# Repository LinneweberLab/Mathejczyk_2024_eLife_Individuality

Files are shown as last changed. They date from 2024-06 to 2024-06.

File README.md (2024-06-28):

Repository for 3 behavioral assays currently in use by the Linneweber lab as described in the paper
“Individuality across environmental context in Drosophila melanogaster (Mathejczyk et al., 2023)". 
https://www.biorxiv.org/content/10.1101/2023.11.26.568741v1
<br>
<br>
This repository contains a part list for off-the-shelve parts, 3D printable files, visual stimulus files, and Matlab scripts for fly tracking and data analyisis.
<br>
<br>

1.	Flight simulator for studying vision-based decision making in flying flies, combining a 360° LED matrix with a magneto-tether apparatus

FlightSim

2.	Indytrax, a compact modular assay and tracker for high-throughput individual ethological quantification
	
IndyTrax

3.	Classical Buridan LED matrix assay

ClassicalBuridan

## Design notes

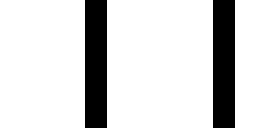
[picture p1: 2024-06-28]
Stripe Stimuli/30deg/30degstripe 0deg front.bmp

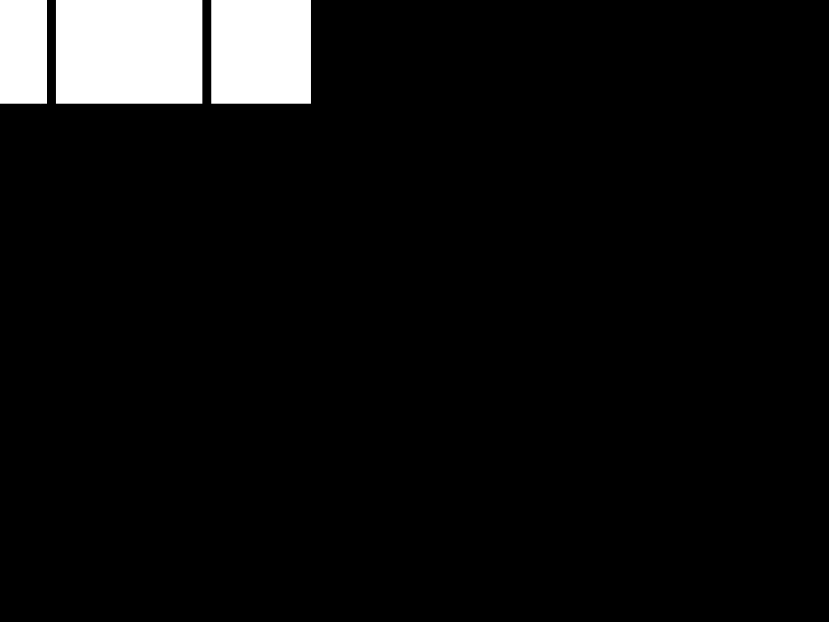
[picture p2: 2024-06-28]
Stripe Stimuli/12deg/BigCylinder 12degstripes Background3.bmp

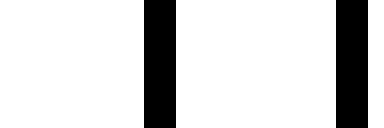
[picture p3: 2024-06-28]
Stripe Stimuli/30deg/BigCylinder 30degstripes.bmp

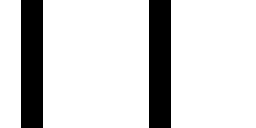
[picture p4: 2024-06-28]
Stripe Stimuli/30deg/30degstripe 90deg sides.bmp

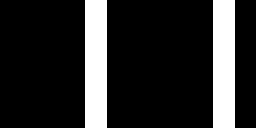
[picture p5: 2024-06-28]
Stripe Stimuli/30deg/30degstripe 0deg front inverted.bmp

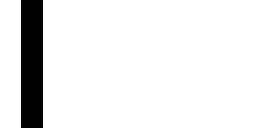
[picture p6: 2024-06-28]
Stripe Stimuli/30deg/30degstripe 90deg sides b.bmp

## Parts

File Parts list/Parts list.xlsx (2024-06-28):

LED Buridan Setup
Nr | Description | Amount
1 | Flir Firefly S FFY-U3-04S2M-C + Edmund optics UC Series Fixed Focal Length Objective (8mm, Stock #33-307) | 1
2 | Acrylic plate white opaque matt 500 x 410 x 3 mm (30mm circular hole in center) | 1
3 | Clear acrylic cylinder (300mm diameter, 300mm height) + diffuser paper or satinice acrylic cylinder (300mm diameter, 300mm height) | 1
4 | Fluorscent tubes (Osram, L 40w, 640C circular cool white) + Osram QT-M 1626–42 controller for AC flicker rate >1kHz | 4
5 | Aluminium profiles black (45 x 45 mm) P45N10LS www.aluprofile24.de:
 | 400mm + thread M12 (min 100mm) profile | 4
 | 480mm profile | 2
 | 485mm profile | 1
 | + Construction accessories www.aluprofile24.de:
 | Wi45x45 angle | 10
 | IWiN10 angle | 20
 | BuMuM8 nut screw | 20
 | FußD40DG m12x100 feet | 4
 | + BitFenix Spectre PRO 230 mm mounted between aluminium rails on 2 opposing sides of the setup for cooling the LED matrix | 8
6 | 6x RGB LED matrix (128 x 64 pixel) www.ledall.de 1x Hdmi controller Novastar mctrl 660 pro + 1x Novastar A8S receiving card 6x | 1
 | + Famotec locating ring 3mm inner diameter (EAN: 4053199955619) + grub screw M3 x 20mm for fixing LED matrix to the LED cylinder | 150
7 | Transparent acrylic dome 120mm diameter (www.architekturbedarf.de) coated with Sigmacote on the inside | 1
8 | PLEXIGLAS® WH10 DC white snow satinice disk 119 x 119 x 10 mm + 850nm LED strip wrapped around edge for backlight illumintaion | 1
9 | Acrylic plate white opaque matt 500 x 500 x 3 mm (120mm circular hole in center) | 1
10 | PLEXIGLAS® WH10 DC white snow satinice 500 x 500 x 3 mm | 1
11 | PLEXIGLAS® WH10 DC white snow satinice disk 119 x 119 x 10 mm + 850nm LED strip (www.ledxess.de) wrapped around edge for backlight illumintaion | 1
12 | PLEXIGLAS® WH10 DC white snow satinice 500 x 500 x 10 mm (300mm circular hole in center) | 2
IndyTrax Setup
Nr | Description | Amount
13 | 120x12mm EEC0381B1-000U-A99 Sunon | 4
14 | 880nm infrared backlight https://www.amazon.de/LED-Lichttherapie-Dunkelrotes-Infrarot-LED-Lichttherapie-Panel-Hautverj%C3%BCngung-Druckentlastung/dp/B07ZQG615D | 1
15 | Server cabinet https://www.serverschrank24.de/15-he-serverschrank-wandgehause-mit-glastur-bxtxh-600-x-450-x-820-mm.html | 1
16 | Translucent acrylic cylinder https://www.kus-kunststofftechnik.de/plexiglas-rohr/plexiglasxt-satiniert-o-60-mm-laenge-waehlbar-von-100-bis-1400-mm/ | 25
16 | Electroluminescent foil A7 white | 50
16 | Transparent dome 50mm https://www.dekoweltcreativ.de/acrylkugel-transparent-teilbar-stueck/p-3330.html | 25
16 | Plexiglas GS white 70% 3mm WH10 49mm diameter https://www.plattenzuschnitt24.de/Plexiglas-GS-weiss-WH10-GT-3mm.html | 50
17 | 19" drawer https://www.it-budget.de/19-Fachboden-ausziehbar-Vollauszug-Tragkraft-30-kg-350-mm-schwarz | 2
18 | Camera Point Grey BFLY-PGE-23S6C-C mounted on Rack chassis 24563-194nVent – Schroff | 1
18 | Objective LM8HC3HOLE 1" 8mm/F1.4 | 1
19 | BitFenix Spectre PRO 230 mm | 2
20 | Carbon heater https://thermowelt.de/Artikel/carbonheater1-1GN-220V.html | 1
Controllers | Humidity controller TXG top-messtechnik.com TMT-HC-210 controlls 40x40mm Sunon EE40101S1-1000U-999 Axiallüfter 12 V/DC placed on (4) | 1
 | PID temperature controller pohltechnic.com RT4-121-Tr21Sd controlls (20) | 1
 | VOLTCRAFT LSP-1165 for controlling IR LED panel (14) and fans (18, 19) | 2
 | TT COMMANDER FT for cooling down enclosure, if necessary (controlls enclosure fans (13)) | 1
 | Inverter https://www.el-light.shop/epages/17778431.sf/de_DE/?ObjectPath=/Shops/17778431/Products/InF1S150 controlls el-foil (16) brightness | 1
LED flight simulator
Nr | Description | Amount
21 | Aluminium profiles black (30 x 30 mm) P30N8 www.aluprofile24.de:
 | 600mm profile | 4
 | 165mm profile | 10
 | 200mm profile | 2
 | + Construction accessories www.aluprofile24.de:
 | PADK30N8B cap | 4
 | IWIN8B angle | 25
 | BuMuM6 nut screw | 10
 | WI30N8B | 10
 | HaKoM6 (12mm) | 20
22 | optional servo motor for dorsal stimulus presentation (Dynamixel MX-12W) + ball bearing 6811-ZZ (www.kugellager-express.de) | 1
23 | 4x RGB LED matrix (128 x 64 pixel) www.ledall.de + 1x Hdmi controller Novastar mctrl 660 pro + 1x Novastar A8S receiving card | 1
 | + Famotec locating ring 3mm inner diameter (EAN: 4053199955619) + grub screw M3 x 20mm for fixing LED matrix to the LED cylinder | 150
24 | Neodynium cylinder magnet (5mm diameter, 20mm height) + white plastic cap + 1mm diameter v-shaped sapphire bearing in center for friction reduction | 1
25 | Neodynium ring magnet (10mm diameter, 5mm height, inner diameter 5mm) + white plastic cap | 1
26 | 850nm near infrared LED array (https://www.amazon.de/POFET-Infrarot-IR-LED-850-nm-Platinenmodul-f%C3%BCr-das-Kamera%C3%Bcberwachungssystem) | 1
27 | Flir Firefly S FFY-U3-04S2M-C + Edmund optics UC Series Fixed Focal Length Objective (12mm, Stock #33-307) | 1
Air puffs | Arduino UNO Rev3 + relais module + Schego membrane pump 300l/h | 1

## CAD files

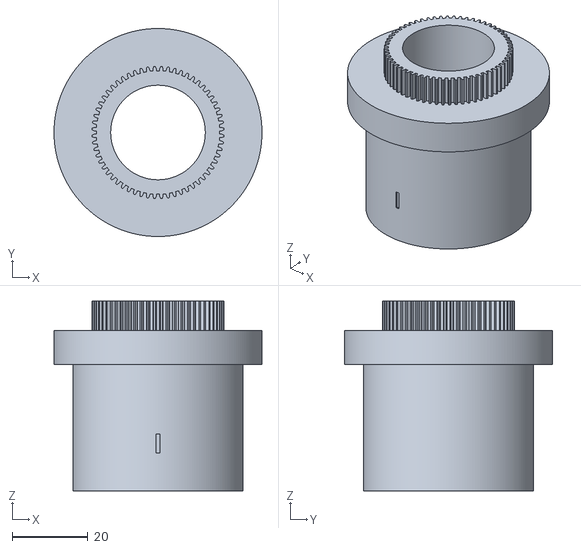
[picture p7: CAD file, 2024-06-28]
3D prints/Flight Sim/6d optional gear 1 upper part.stl
55.0 x 55.0 x 50.2

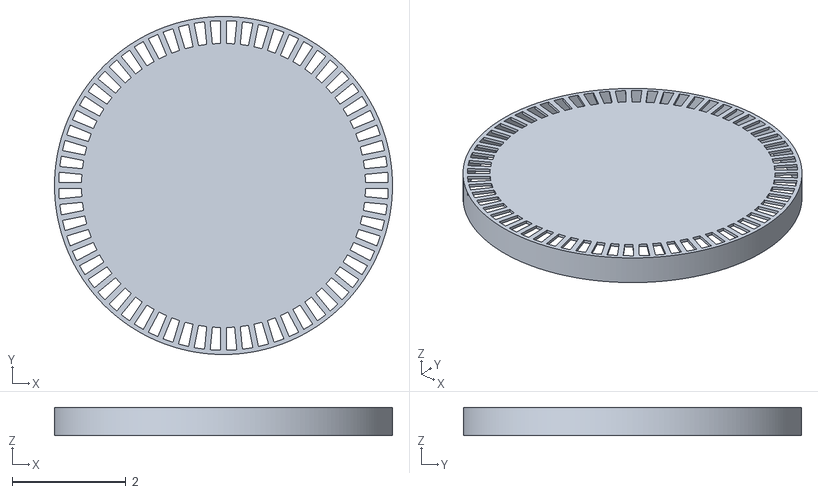
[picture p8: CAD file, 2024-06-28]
3D prints/Indytrax/cylinder cap.stl
5.95 x 5.95 x 0.5

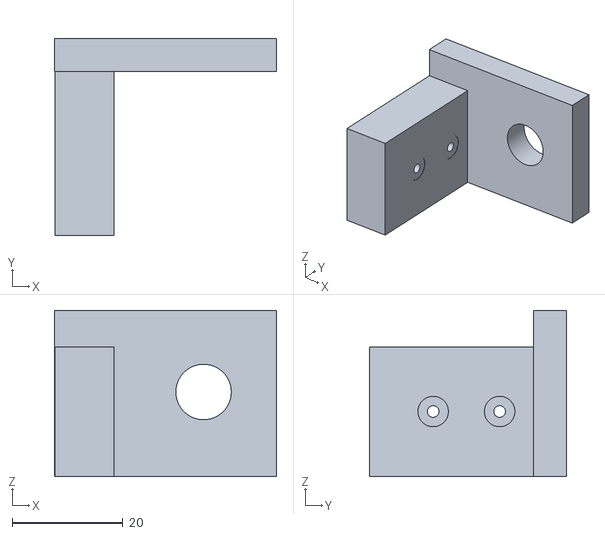
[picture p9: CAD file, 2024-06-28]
3D prints/LED Buridan/cameraholder b.stl
40.1 x 35.6 x 30.0

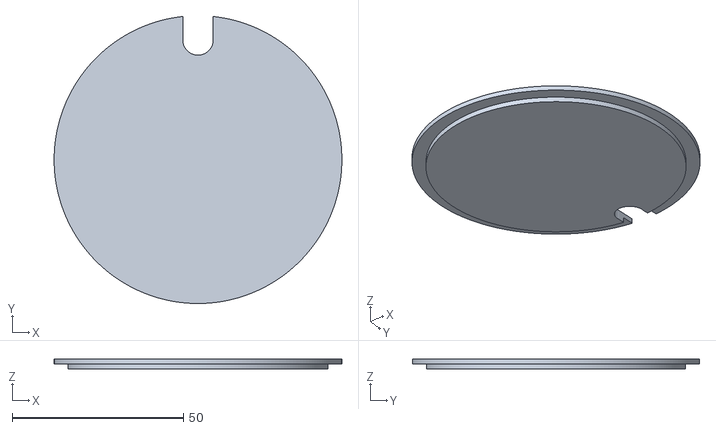
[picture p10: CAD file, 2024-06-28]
3D prints/Flight Sim/6b upper holder lid.stl
84.2 x 83.9 x 3.00

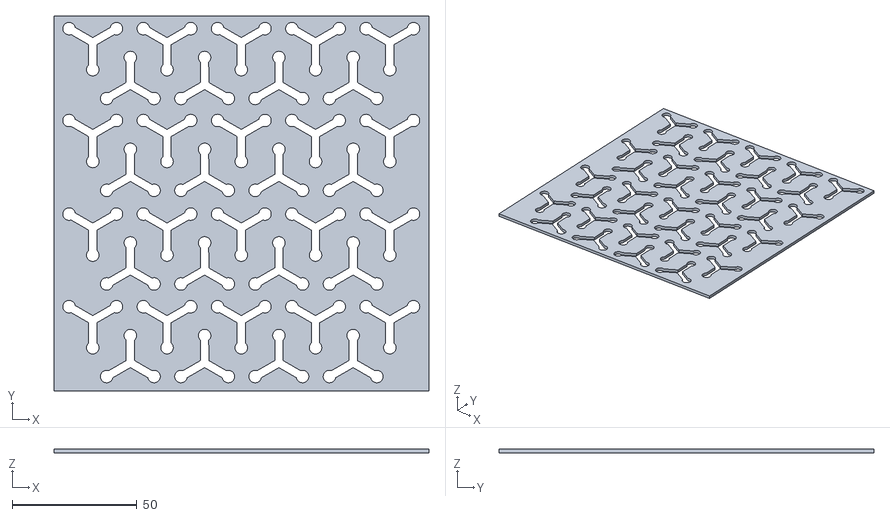
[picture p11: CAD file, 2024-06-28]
3D prints/Indytrax/y-maze plate.stl
150.0 x 150.0 x 1.60

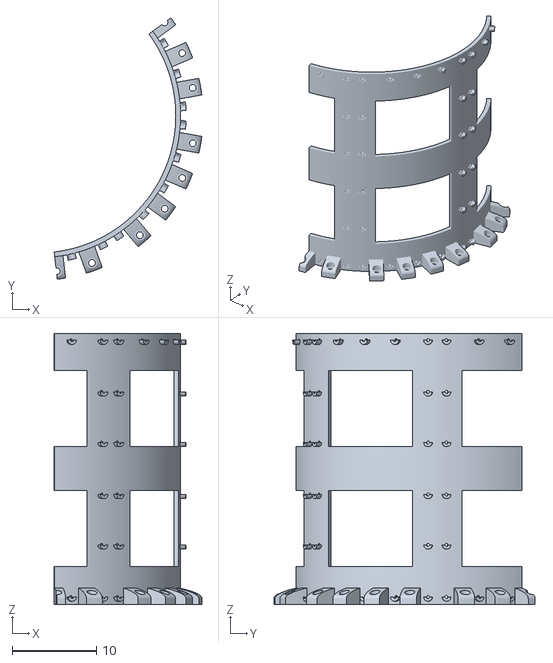
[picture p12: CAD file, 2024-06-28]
3D prints/LED Buridan/1b LED cylinder.stl
17.5 x 31.0 x 32.1

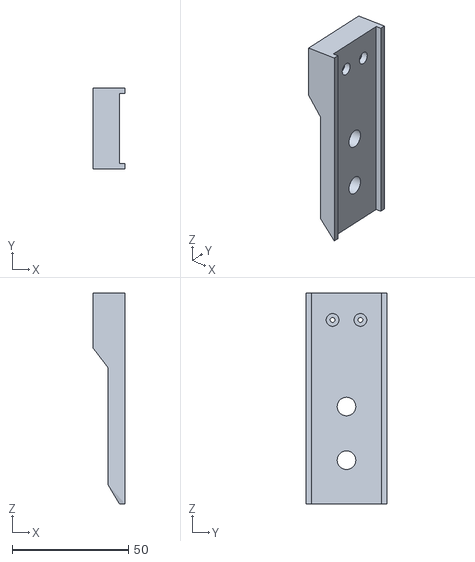
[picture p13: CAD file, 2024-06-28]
3D prints/Flight Sim/11b camera holder.stl
14.0 x 35.0 x 90.9

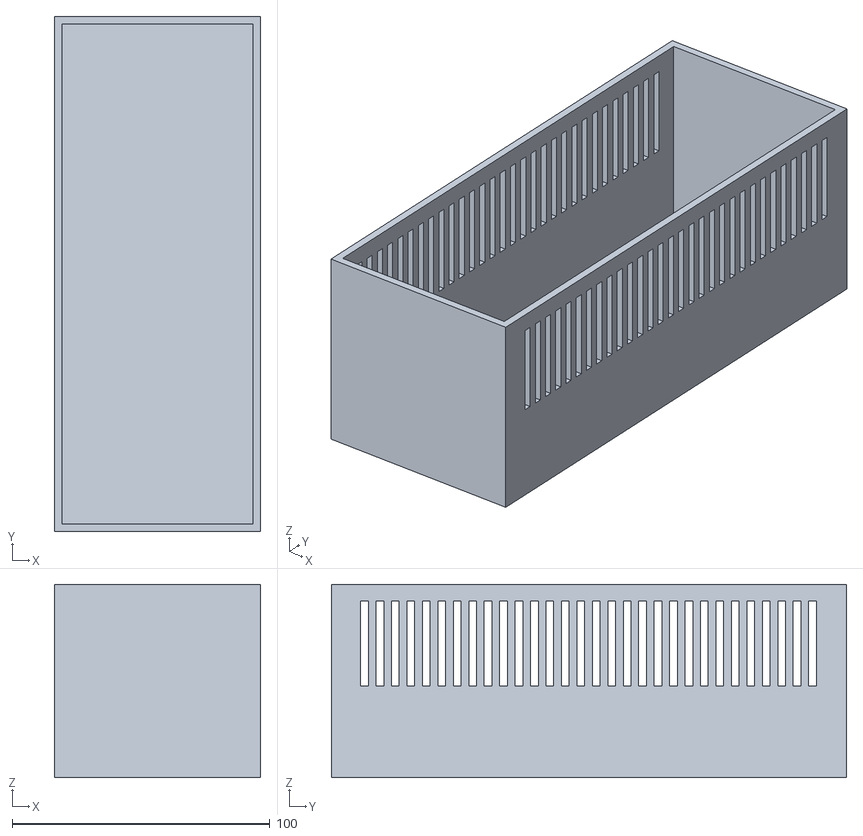
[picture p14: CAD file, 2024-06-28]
3D prints/Indytrax/4a humidifier.stl
80.0 x 200.0 x 75.0

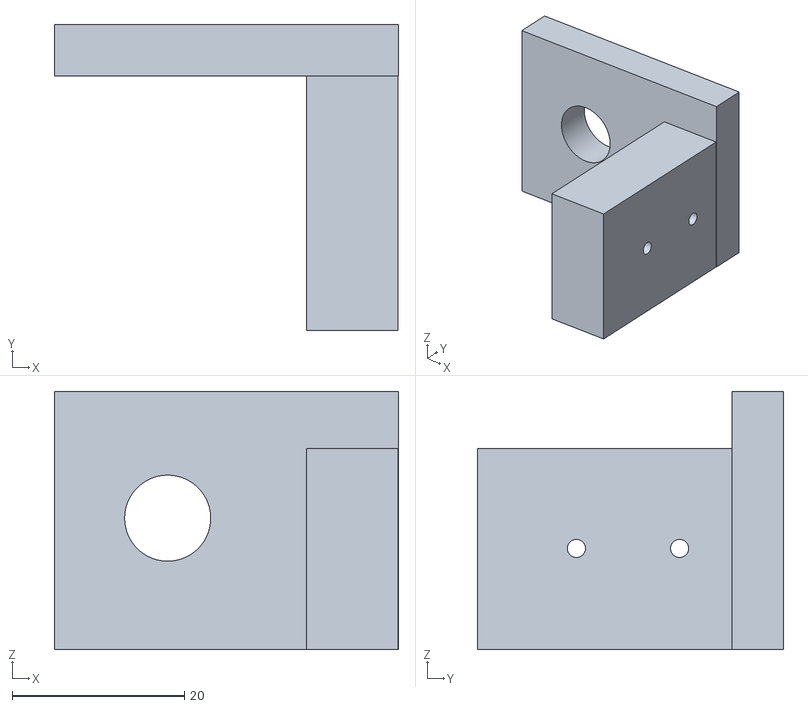
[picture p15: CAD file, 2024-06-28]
3D prints/LED Buridan/cameraholder a.stl
40.0 x 35.6 x 30.0

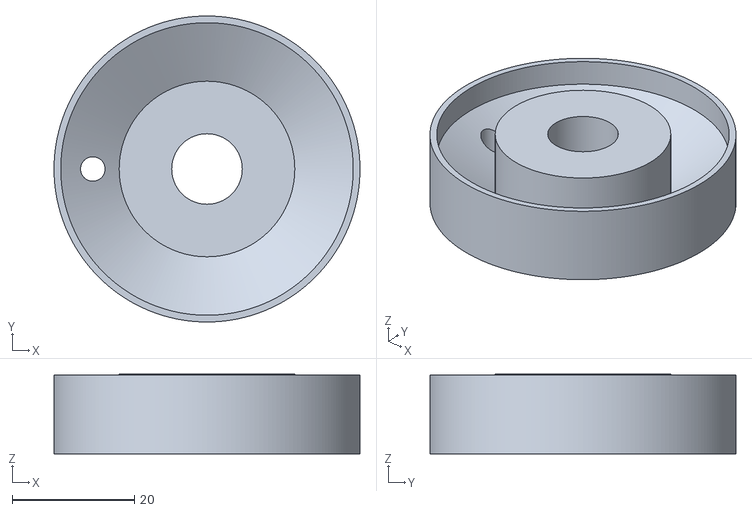
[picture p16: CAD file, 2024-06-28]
3D prints/Flight Sim/8a IR LED base.stl
50.0 x 50.0 x 13.0

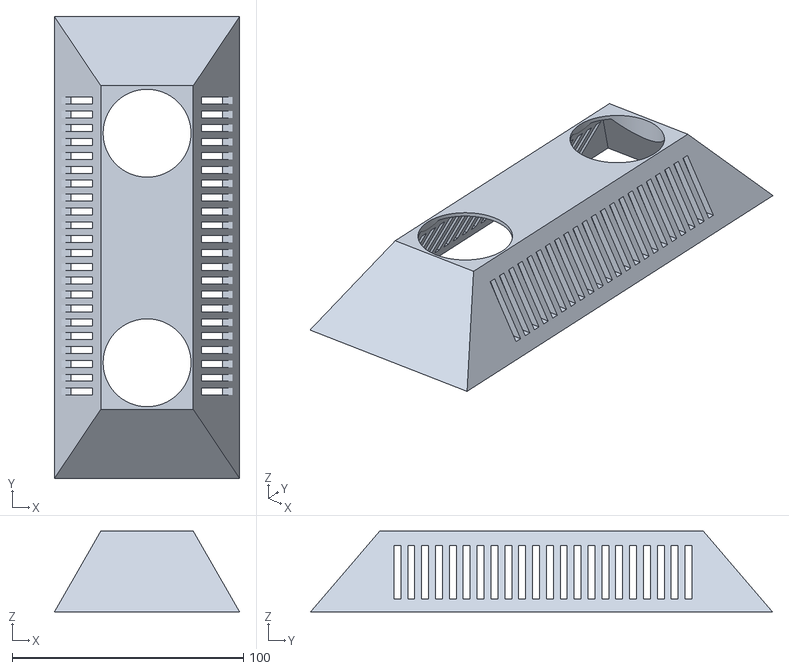
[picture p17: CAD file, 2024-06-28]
3D prints/Indytrax/4b humidifier.stl
80.2 x 199.9 x 35.0

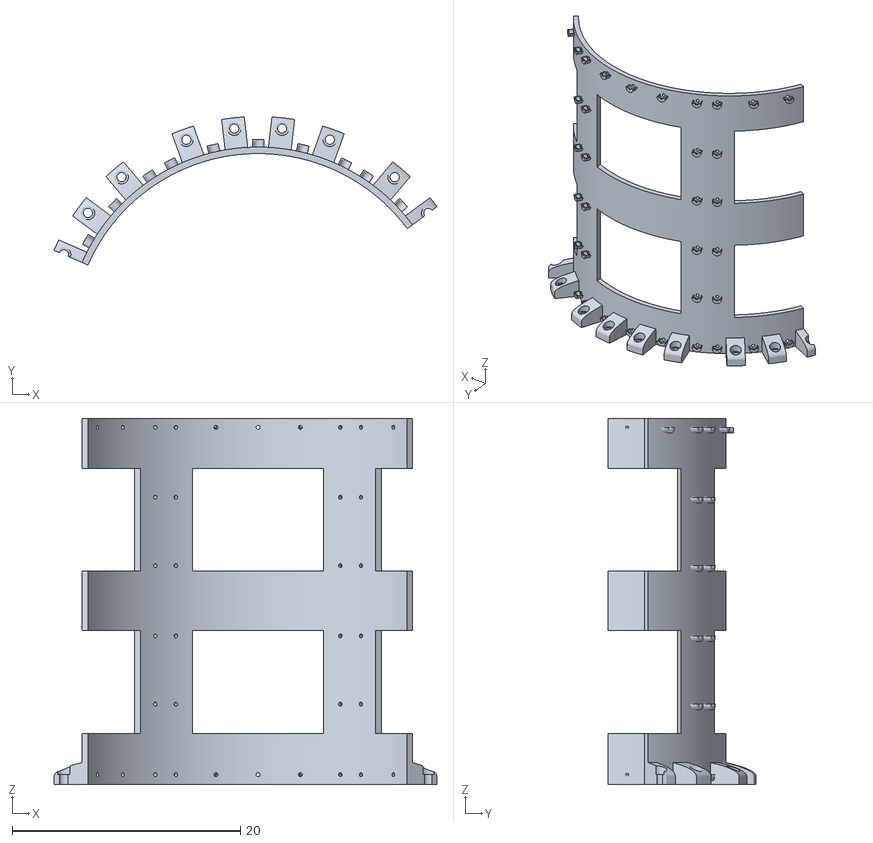
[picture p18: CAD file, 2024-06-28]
3D prints/LED Buridan/1a LED cylinder.stl
33.6 x 13.0 x 32.1

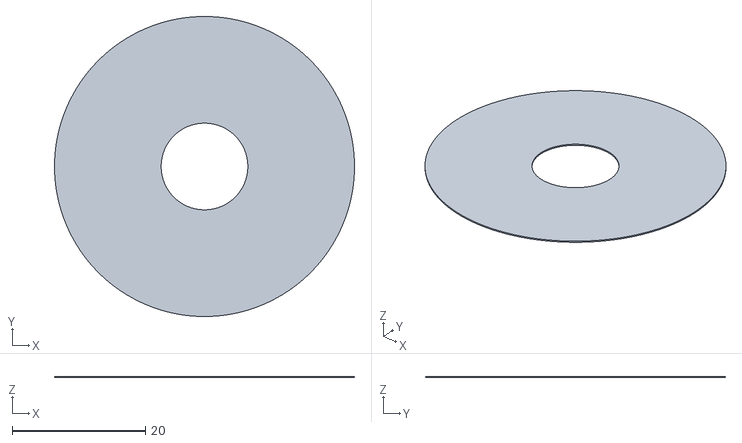
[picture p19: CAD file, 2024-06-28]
3D prints/Flight Sim/8b IR LED cover.stl
45.0 x 45.0 x 0.2

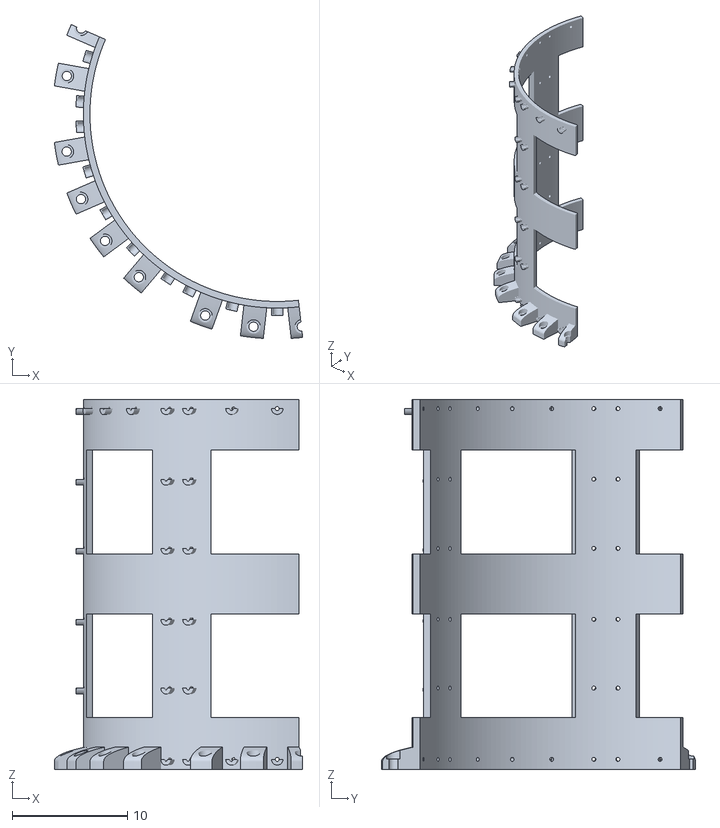
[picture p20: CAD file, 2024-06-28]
3D prints/LED Buridan/1c LED cylinder.stl
21.6 x 27.2 x 32.1

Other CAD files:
3D prints/Flight Sim/11a camera holder.stl
3D prints/Flight Sim/9b IR filter slot.stl
3D prints/Flight Sim/6a upper holder.stl
3D prints/Flight Sim/6c optional LED mount upper part.stl
3D prints/Flight Sim/6e optional gear 2 upper part.stl
3D prints/Flight Sim/7 ring magnet holder.stl
3D prints/Flight Sim/9a filter box.stl
